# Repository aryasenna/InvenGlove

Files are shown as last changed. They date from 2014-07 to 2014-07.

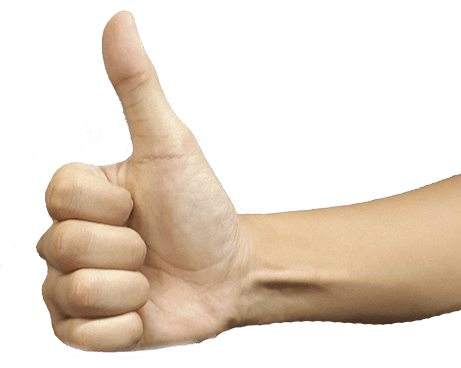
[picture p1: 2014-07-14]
InvenGlove Connector/Resources/turn.png

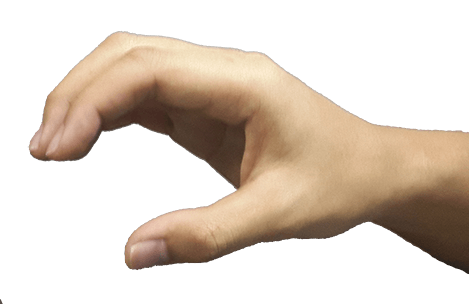
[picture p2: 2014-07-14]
InvenGlove Connector/Resources/half.png

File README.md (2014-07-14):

InvenGlove
==========

An initial prototype of a data glove system for Virtual Assembly. 

InvenGlove captures hand motion and finger flex respectively using Inertial Measurement Unit (IMU)  and flex sensors.  The gloves is to be interfaced with a PC that runs a small program (InvenGlove Connector). This program interprets the sensors readings into object rotation, translation and zoom control inside Autodesk Inventor.

Minimum hardware requirements (barebone):

1x Arduino Mini Pro

2x SpectraSymbol Flex Sensor

1x HC 05 Bluetooth Module

1x InvenSense MPU 9150 Breakout board

(see Eagle PCB schematics and the codes for now, proper documentation should be available soon.)

InvenGlove is part of capstone project on Dept. of Mechanical Engineering, Universitas Indonesia. Released under GNU GPL v3

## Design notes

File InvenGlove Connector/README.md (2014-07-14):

InvenGlove
==========

GitHub Repo for InvenGlove, a prototype glove for Virtual Assembling

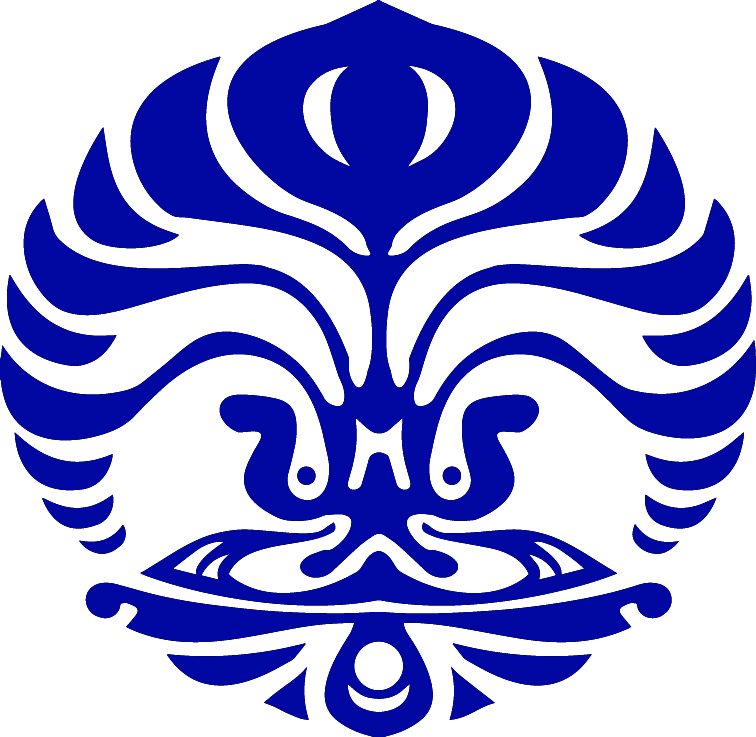
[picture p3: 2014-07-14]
InvenGlove Connector/Resources/makara.png

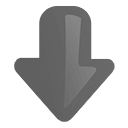
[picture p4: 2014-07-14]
InvenGlove Connector/Resources/downbw.png

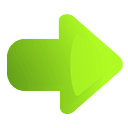
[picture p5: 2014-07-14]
InvenGlove Connector/Resources/right.png

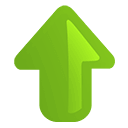
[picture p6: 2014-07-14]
InvenGlove Connector/Resources/up.png

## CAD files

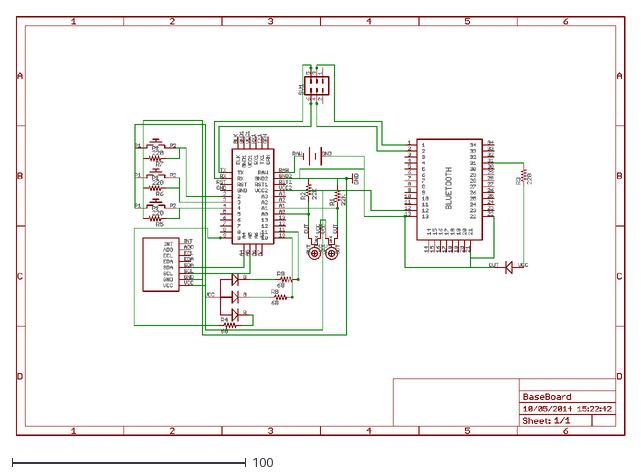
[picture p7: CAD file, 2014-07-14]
Eagle PCB/BaseBoard.dxf
260.6 x 179.4

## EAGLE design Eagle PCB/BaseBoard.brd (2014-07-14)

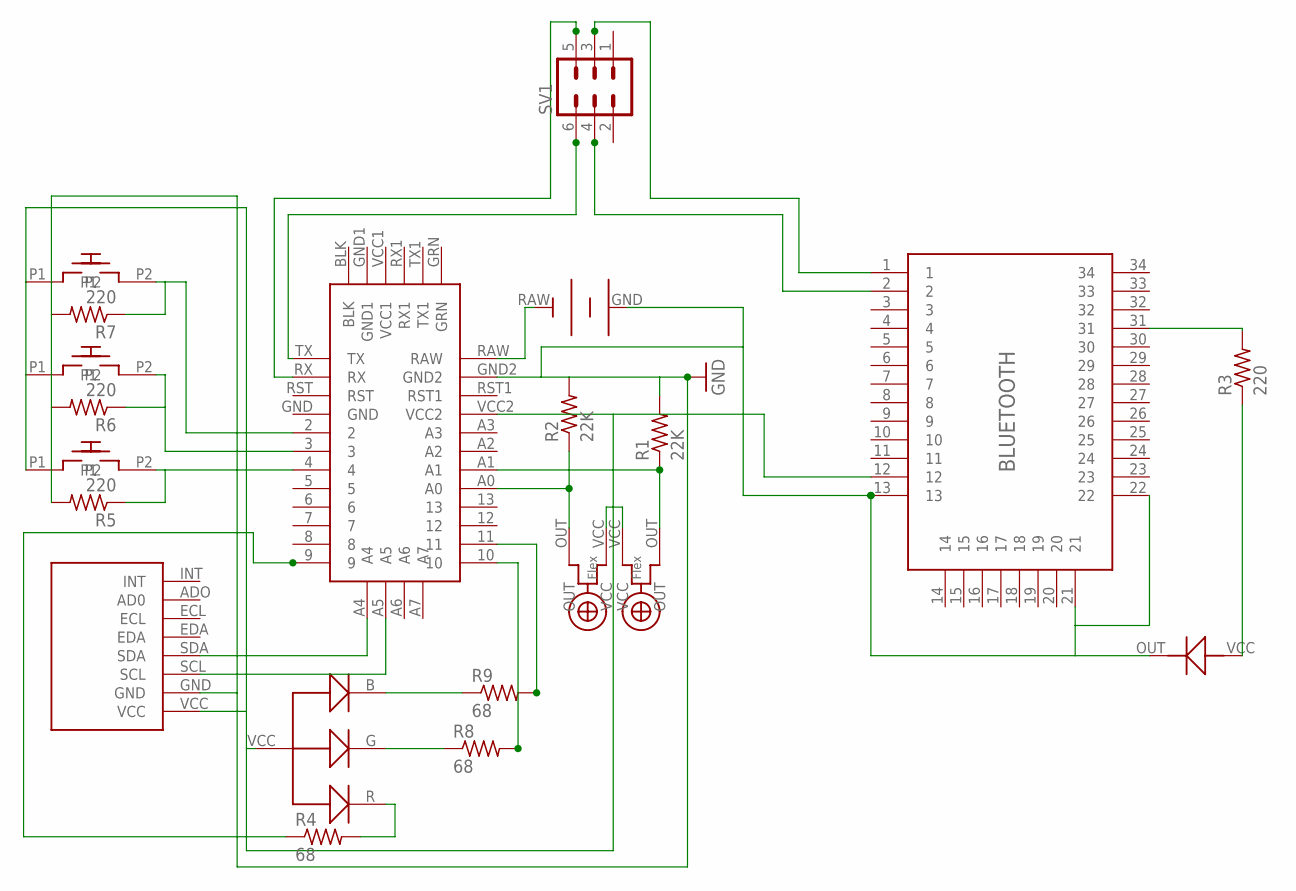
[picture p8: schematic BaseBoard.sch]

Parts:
BLUETOOTH-LED: LED; FLEX
R1, R2: 22K; R1206
R3, R5, R6, R7: 220; R1206
R4, R8, R9: 68; R1206
SV1: MA03-2
TOGGEL: PB
U$1: APM
U$2: MPU-9150
U$3, U$4: FLEX
U$5: BATT; BAT
U$6: BLUETOOTH
U$7: LED-RGB; LED
U$9, U$10: PB

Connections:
GND: BLUETOOTH-LED.OUT (1), R1.2, R2.2, R5.2, R6.2, R7.2, U$1.GND2, U$2.GND, U$5.GND, U$6.13, U$6.21, U$6.22
unnamed: U$1.A4, U$2.SDA
unnamed: U$1.A5, U$2.SCL
unnamed: R8.1, U$7.G
unnamed: R9.1, U$7.B
unnamed: TOGGEL.P1, U$1.VCC2, U$2.VCC, U$3.VCC, U$4.VCC, U$6.12, U$7.VCC, U$9.P1, U$10.P1
unnamed: R2.1, U$1.A0, U$3.OUT
unnamed: R1.1, U$1.A1, U$4.OUT
unnamed: U$1.RAW, U$5.RAW
unnamed: R4.2, U$7.R
unnamed: R3.2, U$6.31
unnamed: BLUETOOTH-LED.VCC (2), R3.1
unnamed: SV1.5, U$1.RX
unnamed: SV1.6, U$1.TX
unnamed: R4.1, U$1.9
unnamed: SV1.3, U$6.1
unnamed: SV1.4, U$6.2
unnamed: R9.2, U$1.11
unnamed: R8.2, U$1.10
unnamed: R5.1, TOGGEL.P2, U$1.4
unnamed: R6.1, U$1.3, U$9.P2
unnamed: R7.1, U$1.2, U$10.P2

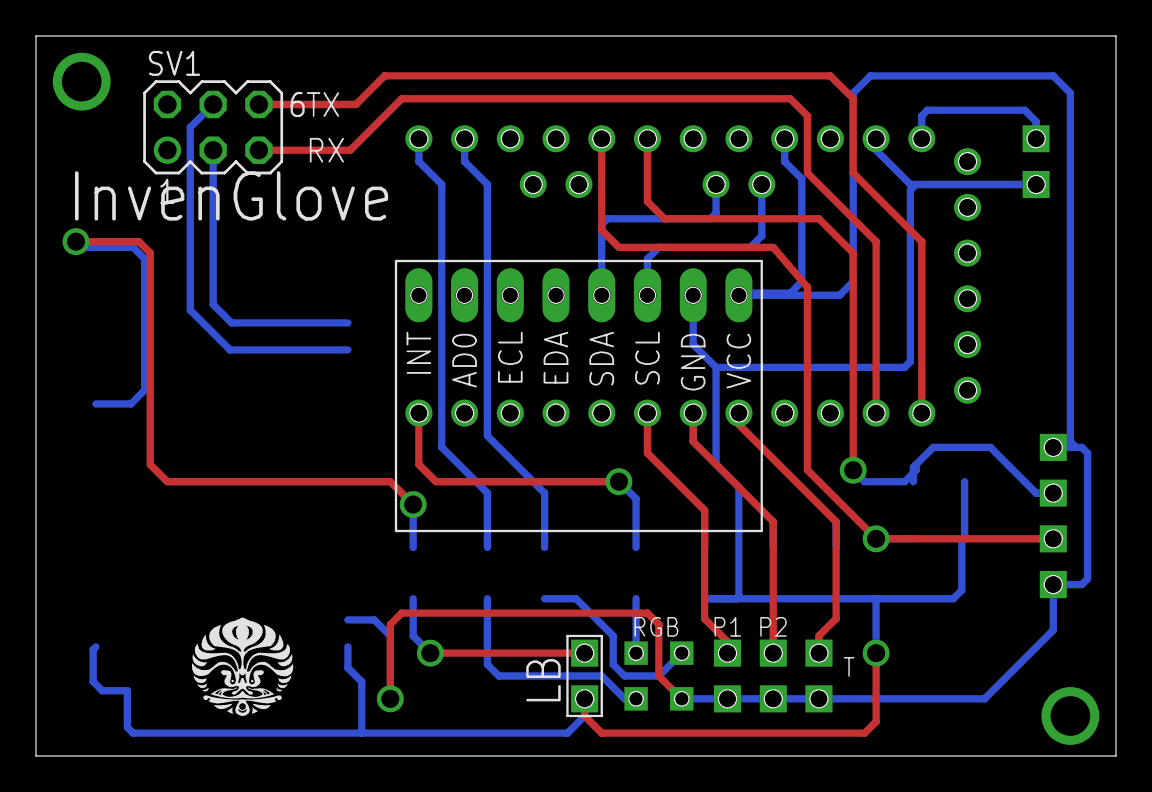
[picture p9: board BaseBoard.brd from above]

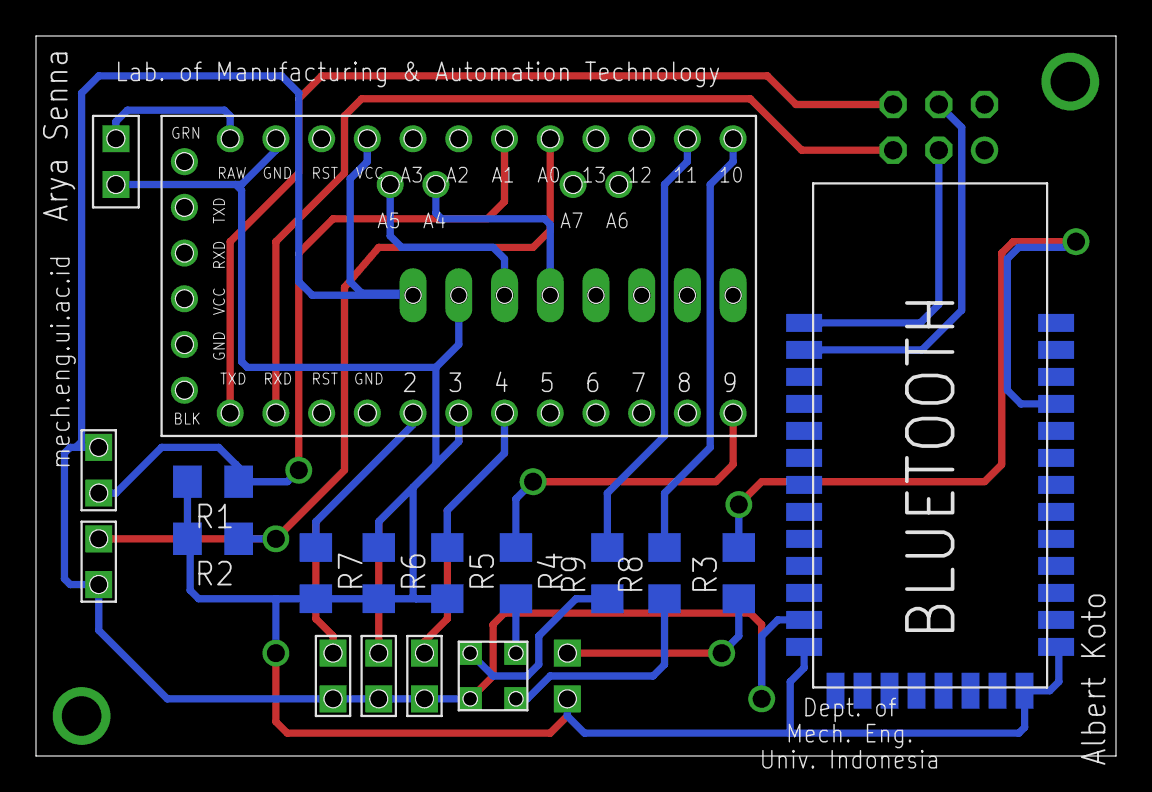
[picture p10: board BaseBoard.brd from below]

Board: 2 copper layers, 60.0 x 40.0 mm, 22 parts (19 on the bottom side), 22 nets.

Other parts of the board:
U$8: MAKARABOTTOM

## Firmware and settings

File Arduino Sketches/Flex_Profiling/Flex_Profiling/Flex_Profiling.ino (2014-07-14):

#include <EEPROM.h>

/*
  Flex Profiling.ino

  Arduino sketches for "InvenGlove" wireless data glove, a wearable virtual assembling tools.
  Flex calibration (hand profiling) module
  Written by Arya Senna
  Finalised on 16 Jun 2014
  V1.0
  Licensed under GNU GPL License v3
  --
  Part of Joint Capstone Project - Mechanical Engineering Department of Universitas Indonesia
  Arya Senna and Albert Koto

  Beta version for latest prototypes. with buttons and RGB LED
*/

#include <Flexion.h>

#define DELIMETER ","
#define addrIndexMinOpen 100
#define addrIndexMaxOpen 102
#define addrThumbMinOpen 104
#define addrThumbMaxOpen 106
#define addrIndexMinHalf 108
#define addrIndexMaxHalf 110
#define addrThumbMinHalf 112
#define addrThumbMaxHalf 114
#define addrIndexMinClosed 116
#define addrIndexMaxClosed 118
#define addrThumbMinClosed 120
#define addrThumbMaxClosed 122
#define addrIndexMinTwist 124
#define addrIndexMaxTwist 126
#define addrThumbMinTwist 128
#define addrThumbMaxTwist 130


//Default threshold
//Min is Max, Max is min of analog value (10 bit adc)
int thresholdIndexMin = 1024;
int thresholdIndexMax = 0;
int thresholdThumbMin = 1024;
int thresholdThumbMax = 0;



int tolerance = 10;
int thresholdIndexMinCal = 1024;
int thresholdIndexMaxCal = 0;
int thresholdThumbMinCal = 1024;
int thresholdThumbMaxCal = 0;

boolean saved;



//Class Init.
Flexion flex;

void setup()
{

 
  
  
  Serial.begin(57600); //115200 is not reliable for mini pro
  Serial.println();
  Serial.println("InvenGlove Finger Flex Profiling");
  Serial.println("Type 's' to temporarily halt calibration process");
  Serial.println("Type 'r' to reset calibration process");
  Serial.println("Type 'c'/'h'/'o'/'t' to save the calibration result (e.g 'o' = save as open)");
  Serial.println("Typing repeatedly might be needed for Arduino to register your command.");
  


}

void loop()
{

  flex.getState();


  if (!saved) 	{


    boolean changed;

    changed = false;
    if (flex.indexReading < thresholdIndexMin) {
      thresholdIndexMin = flex.indexReading;
      changed = true;
    }
    if (flex.indexReading > thresholdIndexMax) {
      thresholdIndexMax = flex.indexReading;
      changed = true;
    }
    if (flex.thumbReading < thresholdThumbMin) {
      thresholdThumbMin = flex.thumbReading;
      changed = true;
    }
    if (flex.thumbReading > thresholdThumbMax) {
      thresholdThumbMax = flex.thumbReading;
      changed = true;
    }

    //give and take threshold to give room for variations
    if (changed) {


      thresholdIndexMinCal = thresholdIndexMin - tolerance;
      thresholdIndexMaxCal = thresholdIndexMax + tolerance;
      thresholdThumbMinCal = thresholdThumbMin - tolerance;
      thresholdThumbMaxCal = thresholdThumbMax + tolerance;

      Serial.println("-------");
      Serial.print("Min. Index Threshold: "); Serial.print(thresholdIndexMinCal); Serial.println();
      Serial.print("Max. Index Threshold: "); Serial.print(thresholdIndexMaxCal); Serial.println();
      Serial.print("Min. Thumb Threshold: "); Serial.print(thresholdThumbMinCal); Serial.println();
      Serial.print("Max. Thumb Threshold: "); Serial.print(thresholdThumbMaxCal); Serial.println();
      Serial.print("Current Calibration:  "); Serial.println(flex.getState());
    }


    if (Serial.available()) {

      if (Serial.read() == 'r') {                  // reset
        Serial.println("RESET");
        thresholdIndexMin = 1024;
        thresholdIndexMax = 0;
        thresholdThumbMin = 1024;
        thresholdThumbMax = 0;
        delay(50);
        saved = false;
      }

      if (Serial.read() == 's') {                  //save none
        Serial.println("Stopped");
        saved = true;
        delay(100);
      }

      if (Serial.read() == 'o') {                  //save open

        
        Serial.println("Open State SAVED");
        flex.WriteCal(addrIndexMinOpen, thresholdIndexMinCal);
        flex.WriteCal(addrIndexMaxOpen, thresholdIndexMaxCal);
        flex.WriteCal(addrThumbMinOpen, thresholdThumbMinCal);
        flex.WriteCal(addrThumbMaxOpen, thresholdThumbMaxCal);
        saved = true;
        
      }


      if (Serial.read() == 'h') {                  //save half
        Serial.println("Half State SAVED");
        flex.WriteCal(addrIndexMinHalf, thresholdIndexMinCal);
        flex.WriteCal(addrIndexMaxHalf, thresholdIndexMaxCal);
        flex.WriteCal(addrThumbMinHalf, thresholdThumbMinCal);
        flex.WriteCal(addrThumbMaxHalf, thresholdThumbMaxCal);
        saved = true;
        
      }

      if (Serial.read() == 'c') {                  //save closed
        Serial.println("Closed state SAVED");
        flex.WriteCal(addrIndexMinClosed, thresholdIndexMinCal);
        flex.WriteCal(addrIndexMaxClosed, thresholdIndexMaxCal);
        flex.WriteCal(addrThumbMinClosed, thresholdThumbMinCal);
        flex.WriteCal(addrThumbMaxClosed, thresholdThumbMaxCal);
        saved = true;
        
      }

      if (Serial.read() == 't') {                  //save twist
        Serial.println("Twist state SAVED");
        flex.WriteCal(addrIndexMinTwist, thresholdIndexMinCal);
        flex.WriteCal(addrIndexMaxTwist, thresholdIndexMaxCal);
        flex.WriteCal(addrThumbMinTwist, thresholdThumbMinCal);
        flex.WriteCal(addrThumbMaxTwist, thresholdThumbMaxCal);
        saved = true;
       
      }

      if (Serial.read() == 'g') {                  //check calibration
        Serial.println("Get Calibration from EEPROM");
        Serial.println("==Open==");
        Serial.print("Min. Index Threshold: "); Serial.print(flex.ReadCal(addrIndexMinOpen)); Serial.println();
        Serial.print("Max. Index Threshold: "); Serial.print(flex.ReadCal(addrIndexMaxOpen)); Serial.println();
        Serial.print("Min. Thumb Threshold: "); Serial.print(flex.ReadCal(addrThumbMinOpen)); Serial.println();
        Serial.print("Max. Thumb Threshold: "); Serial.print(flex.ReadCal(addrThumbMaxOpen)); Serial.println();
        Serial.println();
        Serial.println("==Half==");
        Serial.print("Min. Index Threshold: "); Serial.print(flex.ReadCal(addrIndexMinHalf)); Serial.println();
        Serial.print("Max. Index Threshold: "); Serial.print(flex.ReadCal(addrIndexMaxHalf)); Serial.println();
        Serial.print("Min. Thumb Threshold: "); Serial.print(flex.ReadCal(addrThumbMinHalf)); Serial.println();
        Serial.print("Max. Thumb Threshold: "); Serial.print(flex.ReadCal(addrThumbMaxHalf)); Serial.println();
        Serial.println();
        Serial.println("==Closed==");
        Serial.print("Min. Index Threshold: "); Serial.print(flex.ReadCal(addrIndexMinClosed)); Serial.println();
        Serial.print("Max. Index Threshold: "); Serial.print(flex.ReadCal(addrIndexMaxClosed)); Serial.println();
        Serial.print("Min. Thumb Threshold: "); Serial.print(flex.ReadCal(addrThumbMinClosed)); Serial.println();
        Serial.print("Max. Thumb Threshold: "); Serial.print(flex.ReadCal(addrThumbMaxClosed)); Serial.println();
        Serial.println();
        Serial.println("==Twist==");
        Serial.print("Min. Index Threshold: "); Serial.print(flex.ReadCal(addrIndexMinTwist)); Serial.println();
        Serial.print("Max. Index Threshold: "); Serial.print(flex.ReadCal(addrIndexMaxTwist)); Serial.println();
        Serial.print("Min. Thumb Threshold: "); Serial.print(flex.ReadCal(addrThumbMinTwist)); Serial.println();
        Serial.print("Max. Thumb Threshold: "); Serial.print(flex.ReadCal(addrThumbMaxTwist)); Serial.println();
        Serial.println();
        delay(5000);
      }



    }

  }
}

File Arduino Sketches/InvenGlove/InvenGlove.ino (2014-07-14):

/*
  InvenGlove.ino
  
  Arduino sketches for "InvenGlove" wireless data glove, a wearable virtual assembling tools.
  InvenGlove Add-in for Autodesk Inventor is required.
  Written by Arya Senna
  Finalised on 26 Jun 2014
  V1.5
  Licensed under GNU GPL License v3
  --
  Part of Joint Capstone Project - Mechanical Engineering Department of Universitas Indonesia
  Arya Senna and Albert Koto
  
  Beta version
*/



#include <Flexion.h>
#include <Button.h>
//MPU9150lib

#include <Wire.h>
#include "I2Cdev.h"
#include "MPU9150Lib.h"
#include "CalLib.h"
#include <dmpKey.h>
#include <dmpmap.h>
#include <inv_mpu.h>    
#include <inv_mpu_dmp_motion_driver.h>
#include <EEPROM.h>



//Configuration
#define PB1 4
#define PB2 3
#define TB 2
#define LRED 9
#define LGREEN 11
#define LBLUE 10


#define DELIMETER ","
#define VERBOSE
#define  DEVICE_TO_USE    0
#define MPU_UPDATE_RATE  (20)
#define MAG_UPDATE_RATE  (10)
#define  MPU_MAG_MIX_GYRO_ONLY          0                   // just use gyro yaw
#define  MPU_MAG_MIX_MAG_ONLY           1                   // just use magnetometer and no gyro yaw
#define  MPU_MAG_MIX_GYRO_AND_MAG       10                  // a good mix value 
#define  MPU_MAG_MIX_GYRO_AND_SOME_MAG  50                  // mainly gyros with a bit of mag correction 
#define MPU_LPF_RATE   100 //low pass filter
#define MPU_ACC_SFR   2 //accel sensitivity
#define  SERIAL_PORT_SPEED  57600


//Class Init.
Flexion flex;
MPU9150Lib MPU;
Button pushB1 = Button(PB1, BUTTON_PULLDOWN);
Button pushB2 = Button(PB2, BUTTON_PULLDOWN);
Button toggleB = Button(TB, BUTTON_PULLDOWN);

//method, void and functions

void setup() {
  pinMode(13, INPUT); 
  Serial.begin(SERIAL_PORT_SPEED);
  Wire.begin();
  MPU.selectDevice(DEVICE_TO_USE);                        // only really necessary if using device 1
  MPU.init(MPU_UPDATE_RATE, MPU_MAG_MIX_GYRO_AND_MAG, MAG_UPDATE_RATE, MPU_LPF_RATE, MPU_ACC_SFR);   // start the MPU

#ifdef VERBOSE
Serial.println("Inventor diagnostic (Verbose) mode");
Serial.println("Empty line indicates MPU is not ready to be used. Please check the connection");
Serial.println("Don't forget to switch the toggle to state T2");
#endif
}


void loop() {
  
  if ( MPU.read() && buttonState(toggleB) == 1 ){ //Prevent race conditiion between flex and IMU reading & use physical toggle button
  MPU.selectDevice(DEVICE_TO_USE);                         // only needed if device has changed since init but good form anyway
  #ifndef VERBOSE
  //push button led control and battery indicator
  if (buttonState(pushB1) == 1 ) { setColor(10,30,0); }
  else if (buttonState(pushB2) == 1 ) {  setColor(0,30,10);}
 
  else if (batteryisLow())  { setColor(0,10,0);}

  else {
 setColor(0,10,0);}
   #endif

   
#ifdef VERBOSE
Serial.print("V");
Serial.print(DELIMETER);
Serial.print(flex.indexReading);
Serial.print(DELIMETER);
Serial.print(flex.thumbReading);
Serial.print(DELIMETER);
#endif

#ifndef VERBOSE
  Serial.print(flex.getState()); 

 Serial.print(DELIMETER);
#endif

  MPU.printAnglesDelta(MPU.m_fusedEulerPose);  
    // print the output of the data fusion
  // Serial.print(DELIMETER);
  //MPU.printVectorDelta(MPU.m_calAccel);  
#ifndef VERBOSE
   Serial.print(DELIMETER);

   MPU.printOrientation(MPU.m_fusedEulerPose);
#endif
  
  
  //button serial output
  Serial.print(DELIMETER);
  Serial.print(buttonState(pushB1));
  Serial.print(DELIMETER);
  
    Serial.print(buttonState(pushB2));
  Serial.print(DELIMETER);
  
    Serial.println(buttonState(toggleB));
 
 

}  else if (buttonState(toggleB) == 0) { setColor(0,0,0); }

}
//RGB

void setColor(unsigned int red, unsigned int green,  unsigned int blue)
{
  analogWrite(LRED, 255 - red); 
  analogWrite(LGREEN, 255- green); 
  analogWrite(LBLUE, 255 -blue);  
}


int buttonState(Button button)
{
  
   if(button.isPressed()) {
	return 1;
  }else{
	return 0;
      
  }
  

}
#ifndef VERBOSE
//battery low check
boolean batteryisLow() {
 
  if (flex.readVcc() < 3390) {return true;  }
}
#endif
